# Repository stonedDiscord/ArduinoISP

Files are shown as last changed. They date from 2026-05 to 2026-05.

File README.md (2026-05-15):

# ArduinoISP

A PCB to use an Arduino Nano as an In-Circuit Serial Programmer (ISP) for programming AVR microcontrollers.

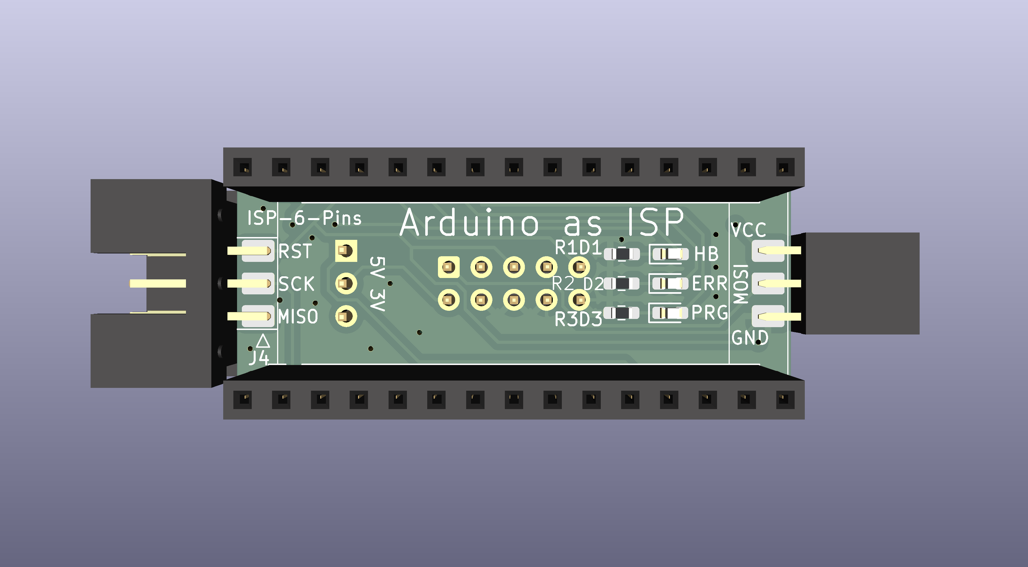
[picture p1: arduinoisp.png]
ArduinoISP PCB


## Overview

This board makes it easier for an Arduino Nano to function as an ISP programmer, enabling you to burn bootloaders to other Arduinos and program AVR chips like the ATmega series, or ATtiny microcontrollers.
To do that, it connects the Arduino Nano correctly to the microcontroller's SPI pins (MOSI, MISO, SCK) and reset pin.
The board is designed in a way that the 6-pin socket header can be directly soldered to the board vertically, while the 10-pin header can accept a flat cable with an adapter on the other end, similiar to the many USBASP clones.

## Hardware

The PCB includes:

- **Two 15-pin headers** for connecting to an Arduino Nano:
  - **J1 (Analog)**: Pins for A0-A7, AREF, 3V3, and power
  - **J2 (Digital)**: Pins for D0-D13, GND, and power
- **AVR-ISP-10 connector (J3)**: Standard 10-pin ICSP programming header for target devices
- **AVR-ISP-6 connector (J4)**: Standard 6-pin ICSP programming header for target devices
- **3 Status LEDs**: Heartbeat, Error and Program
- **Pull-up resistors (R2, R3)**: 220Ω current limiting for LEDs

### Assembly
- Start with the SMD resistors
- Next solder the LEDs
- Then the 2 6-Pin connectors
- Next solder the 10-Pin connector
- Do the 2 Arduino headers last

### Pin Mapping

The ISP programming uses the following connections from the Nano to the 6-pin ICSP connector:

| ISP Pin | Signal | Nano Pin |
|---|---|---|
| 1 | MISO | D12 |
| 2 | VCC | +5V |
| 3 | SCK | D13 |
| 4 | MOSI | D11 |
| 5 | RST | D10 |
| 6 | GND | GND |

The standard ICSP header pinout looks like this, with the key (if present) next to SCK
| | |
|---|---|
| MISO | VCC |
| ] SCK | MOSI |
| RST | GND |

## Usage

### 1. Program the Arduino Nano

1. Open the ArduinoISP sketch: `File > Examples > 11.ArduinoISP > ArduinoISP`
2. Select your Nano board and port
3. Upload the sketch to the Nano

You can also find the sketch on the [official Arduino GitHub page](https://github.com/arduino/arduino-examples/blob/main/examples/11.ArduinoISP/ArduinoISP/ArduinoISP.ino)

### 2. Wire the Boards

Connect the Nano to this PCB's headers. The board will provide the 6-pin ISP connector for connecting to your target device.

### 3. Burn the Bootloader

1. Select the target board type in `Tools > Board`
2. Select `Arduino as ISP` in `Tools > Programmer`
3. Use `Tools > Burn Bootloader`

## Requirements

- Arduino Nano
- Target AVR microcontroller board
- Arduino IDE

## Notes

- Be cautious when programming 3.3V devices (Due, Zero, etc.) - ensure the jumper is set correctly.

## Sponsor
This project is participating in the 2026 [Kicad PCB Design Contest](https://www.pcbway.com/activity/2026-kicad-pcb-design-contest.html).
[You can check out the project on the PCBway website](https://www.pcbway.com/project/shareproject/Arduino_Nano_ISP_Adapter_d65e29b3.html).

## Acknowledgements
- A similiar project for the Arduino Uno can be found at https://github.com/atoomnetmarc/Arduino-as-ISP-shield

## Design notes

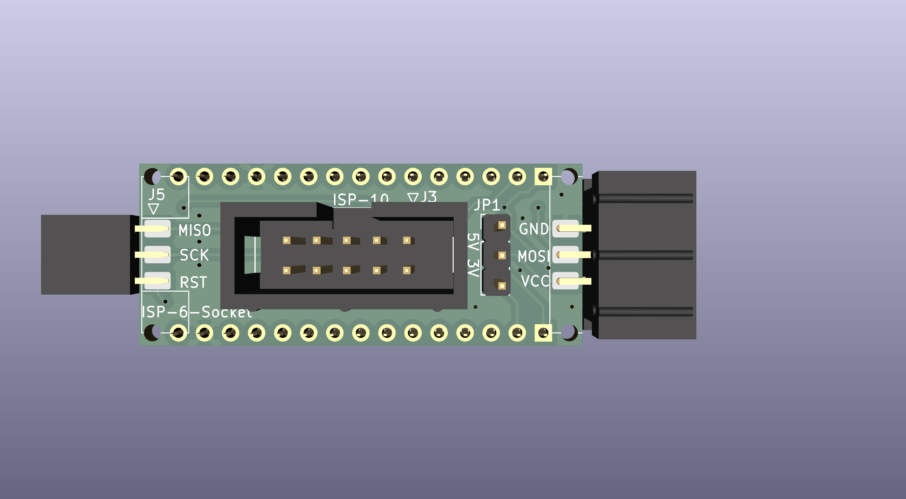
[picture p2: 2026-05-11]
back.png

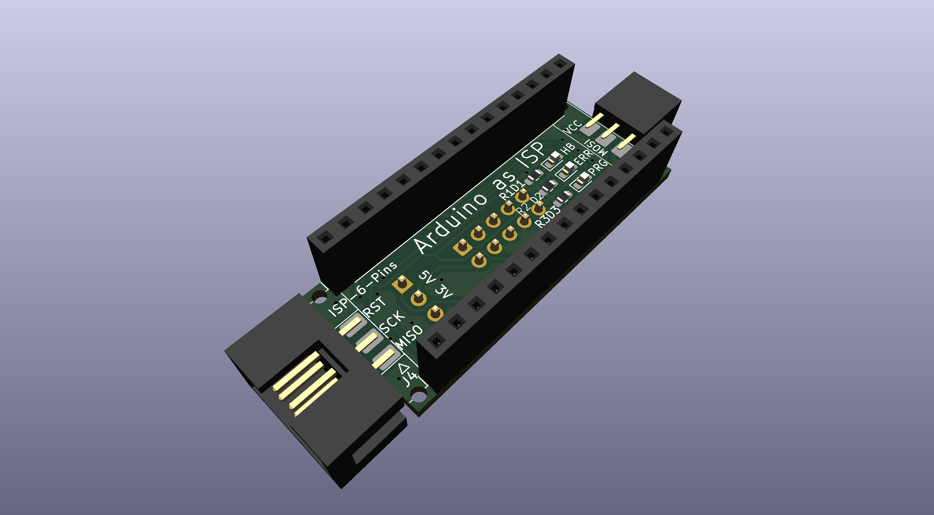
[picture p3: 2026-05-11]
side.png

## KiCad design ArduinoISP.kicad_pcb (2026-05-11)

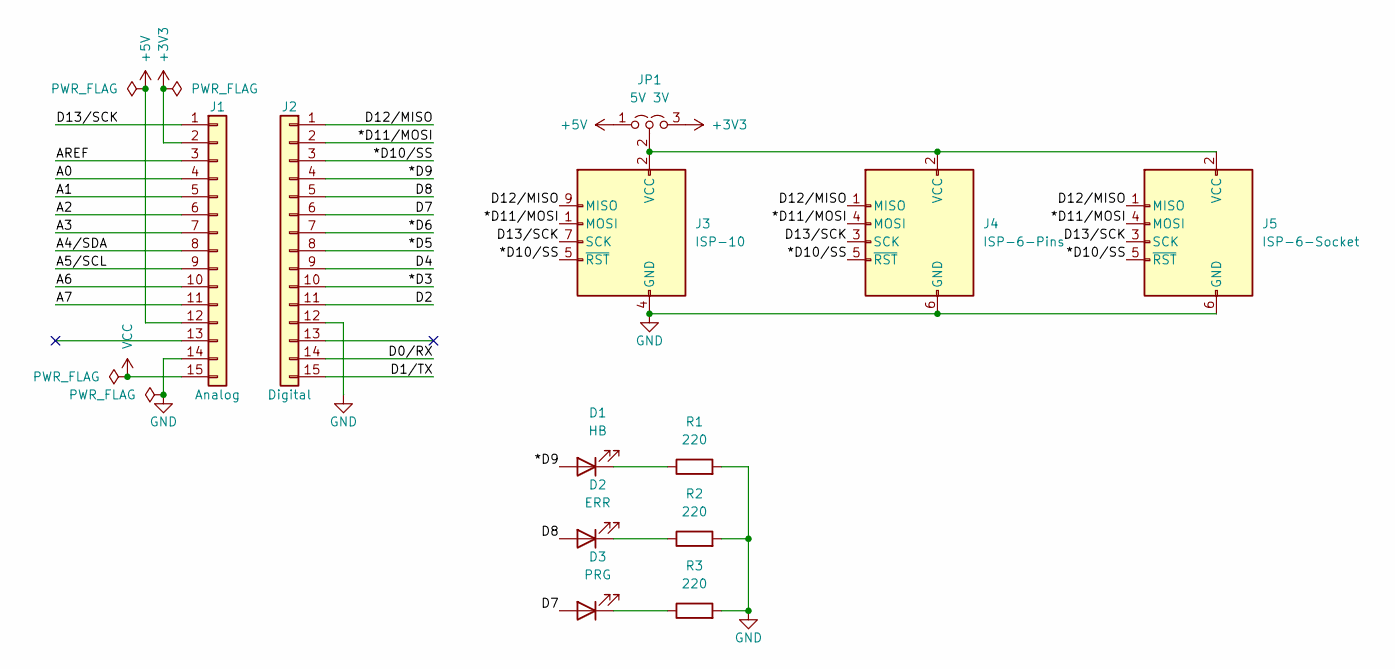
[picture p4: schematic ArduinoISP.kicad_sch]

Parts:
D1: HB; LED_0603_1608Metric_Pad1.05x0.95mm_HandSolder; MPN GL0603UG01
D2: ERR; LED_0603_1608Metric_Pad1.05x0.95mm_HandSolder; MPN GL0603UR01
D3: PRG; LED_0603_1608Metric_Pad1.05x0.95mm_HandSolder; MPN GL0603UY01
J1: Analog; PinSocket_1x15_P2.54mm_Vertical; MPN 2541FV-15P-B
J2: Digital; PinSocket_1x15_P2.54mm_Vertical; MPN 2541FV-15P-B
J3: ISP-10; IDC-Header_2x05_P2.54mm_Vertical; MPN DS1013-10SSiB1-B-0
J4: ISP-6-Pins; IDC-Header_2x03_P2.54mm_Horizontal; MPN DS1013-06SSiB1-B-0
J5: ISP-6-Socket; IDC-Header_2x03_P2.54mm_Horizontal; MPN DS1023-32-2x3V8
JP1: 5V 3V; PinHeader_1x03_P2.54mm_Vertical; MPN 2541WV-03P
R1, R2, R3: 220; R_0603_1608Metric_Pad0.98x0.95mm_HandSolder; MPN FRC0603F2200TS

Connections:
+3V3: J1.2, JP1.3 (B)
+5V: J1.12, JP1.1 (A)
/*D3: J2.10
/*D5: J2.8
/*D6: J2.7
/*D9: D1.2 (A), J2.4
/*D10/SS: J2.3, J3.5 (~RST), J4.5 (~RST), J5.5 (~RST)
/*D11/MOSI: J2.2, J3.1 (MOSI), J4.4 (MOSI), J5.4 (MOSI)
/A0: J1.4
/A1: J1.5
/A2: J1.6
/A3: J1.7
/A4/SDA: J1.8
/A5/SCL: J1.9
/A6: J1.10
/A7: J1.11
/AREF: J1.3
/D0/RX: J2.14
/D1/TX: J2.15
/D2: J2.11
/D4: J2.9
/D7: D3.2 (A), J2.6
/D8: D2.2 (A), J2.5
/D12/MISO: J2.1, J3.9 (MISO), J4.1 (MISO), J5.1 (MISO)
/D13/SCK: J1.1, J3.7 (SCK), J4.3 (SCK), J5.3 (SCK)
GND: J1.14, J2.12, J3.4 (GND), J3.6 (GND), J3.8 (GND), J3.10 (GND), J4.6 (GND), J5.6 (GND), R1.2, R2.2, R3.2
unnamed: D1.1 (K), R1.1
unnamed: D2.1 (K), R2.1
unnamed: D3.1 (K), R3.1
unnamed: J3.2 (VCC), J4.2 (VCC), J5.2 (VCC), JP1.2 (C)
VCC: J1.15

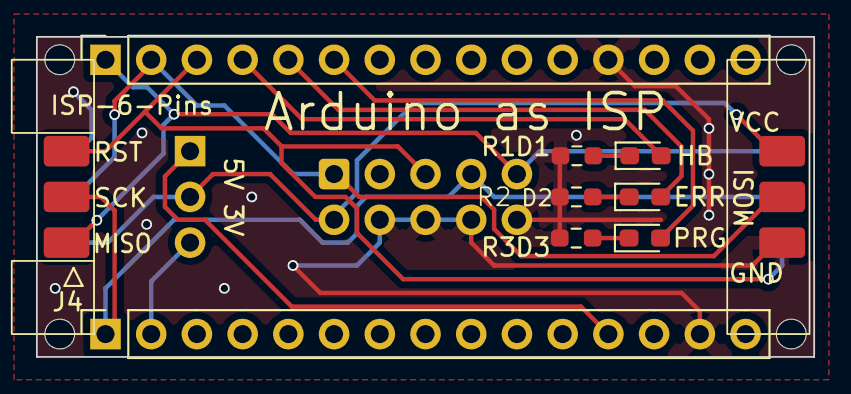
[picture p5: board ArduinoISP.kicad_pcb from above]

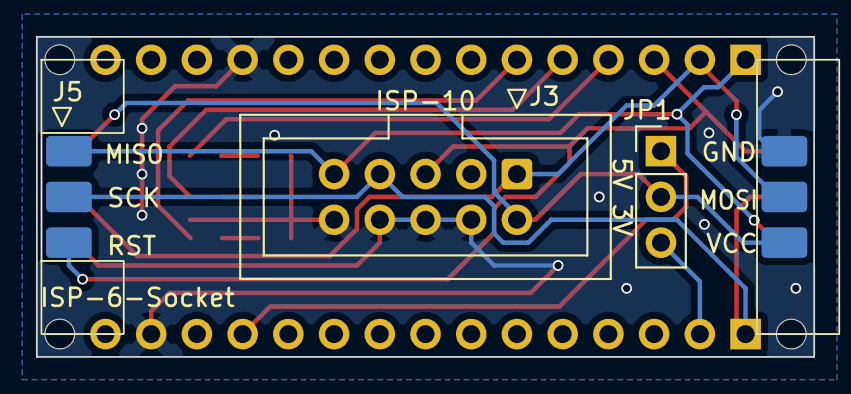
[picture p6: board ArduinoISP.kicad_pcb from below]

Board: 2 copper layers, 43.2 x 17.8 mm, 16 parts (3 on the bottom side), 14 nets.

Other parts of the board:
MH1, MH2, MH3, MH4: MountingHole_65mil

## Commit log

2026-05-11 move project files from automatenplatinen
    [ArduinoISP.kicad_pcb, ArduinoISP.kicad_sch]
2026-05-11 add footprints
2026-05-11 try double ended
    [ArduinoISP.kicad_pcb, ArduinoISP.kicad_sch]
2026-05-11 redo board
    [ArduinoISP.kicad_pcb]
2026-05-11 part numbers
    [ArduinoISP.kicad_pcb, ArduinoISP.kicad_sch]
